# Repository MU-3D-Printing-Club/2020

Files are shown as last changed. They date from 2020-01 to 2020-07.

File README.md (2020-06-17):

# 2020
Meetings 2pm Thursday in E3508.

[Link to Ada Assembly instructions](https://openbionicslabs.com/obtutorials/ada-v1-assembly)

## Updates 2/27/2020
- Please remember to always **PULL FROM ORIGIN** and make a new branch before you make edits.
- Installed gitHub, Eagle, and SolidWorks on lab computer

## V2
Stuart's ARM board and probably Rust code.
- [x] Ask Dr. Gillis for review. (JD)
- [ ] Get rust code running for servos on discovery board. PWM libraries and also [potentiometer controlled feedback](https://www.actuonix.com/Actuonix-PQ-12-P-Linear-Actuator-p/pq12-p.htm). (Chris/Jake/Stuart/James/Matt)
- [x] Identify which rust-compatible chip to buy. (Jake/Stuart)
## V1
### V1.3 

Added [boost regulator](http://ww1.microchip.com/downloads/en/DeviceDoc/20005572A.pdf) in addition to 1.2 changes.  
- [ ] Review Ahmad's suggestions. Look in "Regulator" branch. (Jake/Ethan)
- [ ] Make Vcc route bigger.
### V1.2
Added [LiPo](https://cdn.sparkfun.com/assets/learn_tutorials/6/9/5/MCP738312.pdf) charger.

- [ ] Solder chip and resistors on.
- [ ] Burn bootloader and code. See if it works.
- [ ] Research new trigger algorithm. (James/Matt)
- [ ] Research custom myoelectric sensor. (Rosie)
- [ ] PALM DESIGN! (Chris, Hannah, Colm)
### V1.1
Reorganized PCB. Larger back cover.

- [ ] Document
- [ ] SHIP.
- [x] Tie knots. (Jack)
- [x] Solder myoelectric in.
- [x] Attach servos.
- [x] Print back cover.
- [x] Epoxy screw in.
- [x] Get the programmer out of reset mode. (Stuart)

### V1.0
From December. Broke because of lack and space/organization in back cover.

## V0
Bare bones code and prototype back cover. Cannot find Eagle file. Only legend speaks of this.

<pre>
.
├── Datasheets
│   ├── Actuonix+PQ12+Datasheet.pdf
│   ├── MCP73831.pdf
│   └── STM32F303.pdf
├── Myosensor
│   ├── Myosense.v1.brd
│   └── Myosense.v1.sch
├── Old
│   ├── Eagle Libraries
│   │   └── 3DPC.lbr
│   ├── Jig Components
│   │   ├── Legiment Jig.SLDPRT
│   │   └── Legiment Jig.STL
│   ├── eletronics test bed
│   │   ├── 400 point breadboard holder.stl
│   │   ├── STM32F3DISCOVERY holder.stl
│   │   ├── actuonix PQ12 servo holder.stl
│   │   ├── battery holder.stl
│   │   └── electronics v1.0 holder.stl
│   ├── v0.0
│   │   ├── SolidWorks
│   │   │   ├── Backcover 12-6-19.SLDPRT
│   │   │   └── Backcover 12-6-19.STL
│   │   ├── myoFlex-Original
│   │   │   └── myoFlex.ino
│   │   └── pcb
│   │       ├── circuitdraft.brd
│   │       ├── circuitdraft.sch
│   │       └── eagle.epf
│   ├── v0.1
│   │   └── PCB
│   │       ├── circuitdraft.brd
│   │       ├── circuitdraft.sch
│   │       └── eagle.epf
│   ├── v1.0
│   │   ├── PCB
│   │   │   ├── circuitdraft.brd
│   │   │   ├── circuitdraft.sch
│   │   │   └── eagle.epf
│   │   ├── PCB Libraries
│   │   │   ├── SamacSys_Parts.lbr
│   │   │   ├── TPS54627DDAR.lbr
│   │   │   ├── charger.lbr
│   │   │   ├── ind2.lbr
│   │   │   ├── inductor.lbr
│   │   │   ├── mega32U4.lbr
│   │   │   ├── microchip-update.lbr
│   │   │   └── powerPad.lbr
│   │   ├── SolidWorks
│   │   │   ├── 191216_Backcover_JD.SLDPRT
│   │   │   └── 191216_Backcover_JD.STL
│   │   ├── circuitdraft.txt
│   │   └── mainCode
│   │       └── mainCode.ino
│   ├── v1.1
│   │   ├── CAD
│   │   │   ├── 02_18_2020_BackcoverC.SLDPRT
│   │   │   ├── 02_18_2020_BackcoverF.SLDPRT
│   │   │   ├── 02_18_2020_BackcoverF.STL
│   │   │   ├── 2020_03_02_BackcoverShell.SLDPRT
│   │   │   ├── 203101_Backcover.SLDPRT
│   │   │   ├── Front Face Palm Screen Capture.PNG
│   │   │   ├── New Palm STL.STL
│   │   │   ├── New Palm.SLDPRT
│   │   │   ├── R_palm.SLDPRT
│   │   │   └── R_palm.stl
│   │   ├── Code
│   │   │   ├── Blink
│   │   │   │   └── Blink.ino
│   │   │   ├── helloWorld
│   │   │   │   └── helloWorld.ino
│   │   │   ├── mainCode
│   │   │   │   └── mainCode.ino
│   │   │   └── servoTest
│   │   │       └── servoTest.ino
│   │   └── PCB
│   │       ├── circuitdraft.brd
│   │       ├── circuitdraft.sch
│   │       └── eagle.epf
│   ├── v1.2
│   │   ├── Notes.txt
│   │   ├── PCB
│   │   │   ├── circuitdraft.brd
│   │   │   ├── circuitdraft.sch
│   │   │   └── eagle.epf
│   │   ├── mainCode
│   │   │   └── mainCode.ino
│   │   └── testLiPoCharger
│   │       └── testLiPoCharger.ino
│   ├── v1.3
│   │   ├── circuitdraft.brd
│   │   └── circuitdraft.sch
│   ├── v2.0
│   │   └── PCB
│   │       ├── Hand v2.0 parts.lib
│   │       ├── Hand v2.0-cache.lib
│   │       ├── Hand v2.0-rescue.dcm
│   │       ├── Hand v2.0.kicad_pcb
│   │       ├── Hand v2.0.kicad_pcb-bak
│   │       ├── Hand v2.0.net
│   │       ├── Hand v2.0.sch
│   │       ├── Hand v2.0.sch-bak
│   │       ├── fp-info-cache
│   │       ├── hand parts.bck
│   │       ├── hand parts.dcm
│   │       └── sym-lib-table
│   └── v2.1
│       └── PCB
│           ├── 2020-02-01_02-22-13
│           │   ├── 2020-02-01_02-22-13.lib
│           │   ├── footprints.pretty
│           │   │   └── STM32F302_303C2.kicad_mod
│           │   └── readme.txt
│           ├── Hand v2.1 parts.lib
│           ├── Hand v2.1-cache.lib
│           ├── Hand v2.1-rescue.dcm
│           ├── Hand v2.1-rescue.lib
│           ├── Hand v2.1.kicad_pcb
│           ├── Hand v2.1.kicad_pcb-bak
│           ├── Hand v2.1.net
│           ├── Hand v2.1.sch
│           ├── Hand v2.1.sch-bak
│           ├── fp-info-cache
│           ├── hand parts.bck
│           ├── hand parts.dcm
│           └── sym-lib-table
├── README.md
├── tree.txt
├── treeCMD.txt
└── v3.0
    └── hand v3.0
        ├── Hand Parts.bck
        ├── Hand Parts.dcm
        ├── Hand Parts.lib
        ├── fp-info-cache
        ├── hand v3.0-cache.lib
        ├── hand v3.0.kicad_pcb
        ├── hand v3.0.sch
        ├── hand v3.0.sch-bak
        ├── hand v3.xml
        └── sym-lib-table

38 directories, 103 files

</pre>
tree -I "*.pro|*.b#?|*.s#?|*.l?|*.job" -o tree.txt

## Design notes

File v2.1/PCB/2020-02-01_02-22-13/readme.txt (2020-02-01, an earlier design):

 

**********************************************************
*************  Important Instructions Follow  ************
**********************************************************
 
All files exported to: C:\UltraLibrarian\Library\Exported\KiCad\2020-02-01_02-22-13\2020-02-01_02-22-13\2020-02-01_02-22-13.lib

After you have used Ultra Librarian to export library:
**************************************************
**To import your new library symbols into KiCad:**
**************************************************
1. Open KiCad.
2. On the program/tool list, select the Symbol Library Editor.
3. In the Symbol Library Editor, select 'Add an existing library' from the symbol menu or "Add Library" from the File menu.
4. From here select the library you wish to add.
5. Now select if you would like the library accessible globaly or for the current project.
6. Browsing the list of libraries, you should see the newly imported library!

**************************************************************
**To import your new library footprints/patterns into KiCad:**
**************************************************************
1. Open KiCad.
2. On the program/tool list, go to Pcbnew, or simply open the footprint editor.
3. Select the "import footprint" icon then select the *.kicad_mod* file of the footprint to be imported.
4. You have now successfully imported your new footprint/pattern.

**************************************************************
**    !!!!!!!!!!!!!        WARNING        !!!!!!!!!!!!!     **
**************************************************************
KiCAD does not support filled/hatched polygons on footprints!
All polygons will be represented with an outline made of lines in each design.
Etch polygons will be drawn on the documentation layer, "Dwgs.User", and can be filled during board creation.

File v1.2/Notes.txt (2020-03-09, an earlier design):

1. Buy higher geared servos
2. Make algorithm not move all hands at the same time.
3. Make power path bigger.

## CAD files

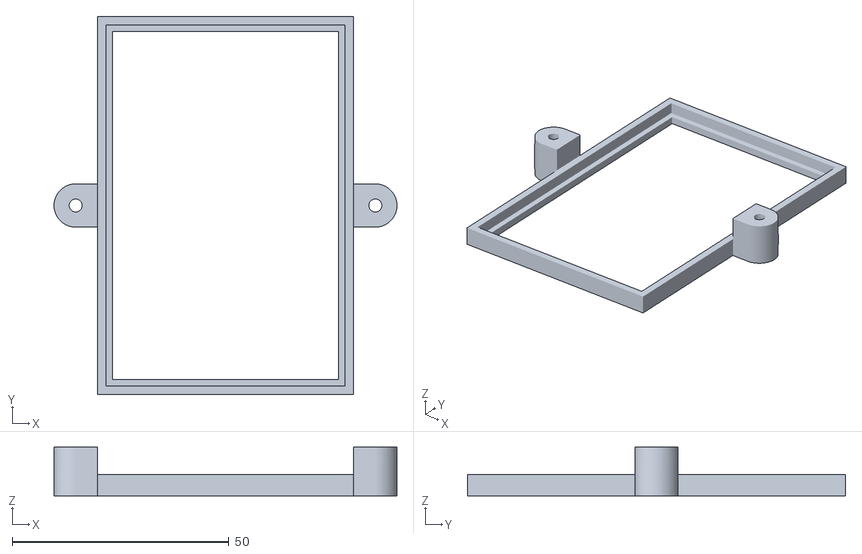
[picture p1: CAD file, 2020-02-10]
eletronics test bed/400 point breadboard holder.stl
79.2 x 87.3 x 11.3

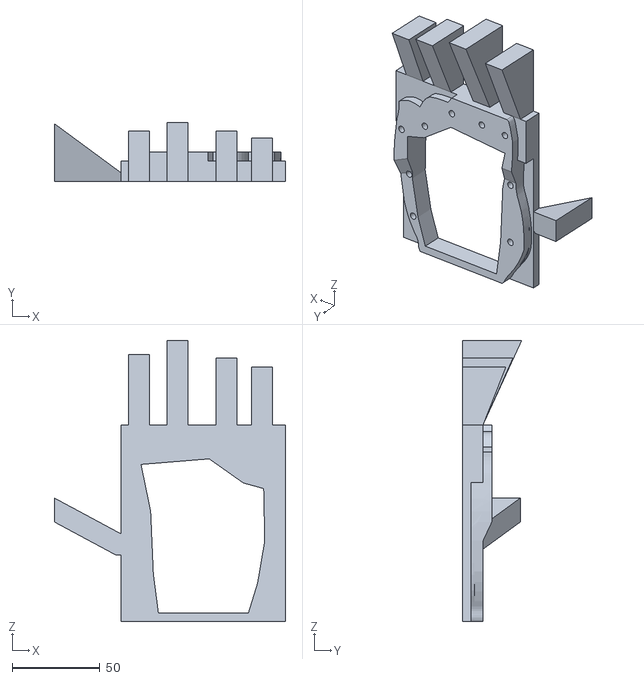
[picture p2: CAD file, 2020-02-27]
Jig Components/Legiment Jig.STL
131.5 x 33.8 x 159.9

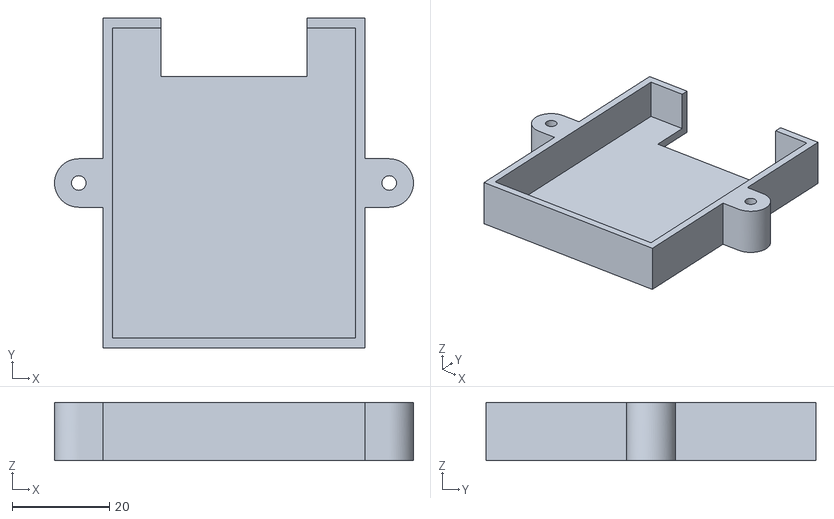
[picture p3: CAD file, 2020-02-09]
eletronics test bed/battery holder.stl
74.0 x 68.0 x 12.0

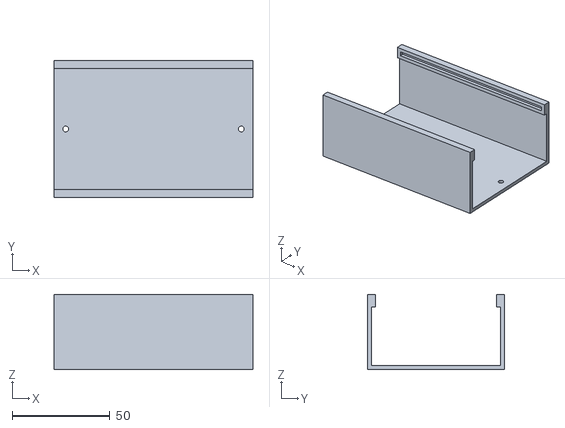
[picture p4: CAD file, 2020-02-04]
eletronics test bed/STM32F3DISCOVERY holder.stl
102.0 x 70.0 x 38.5

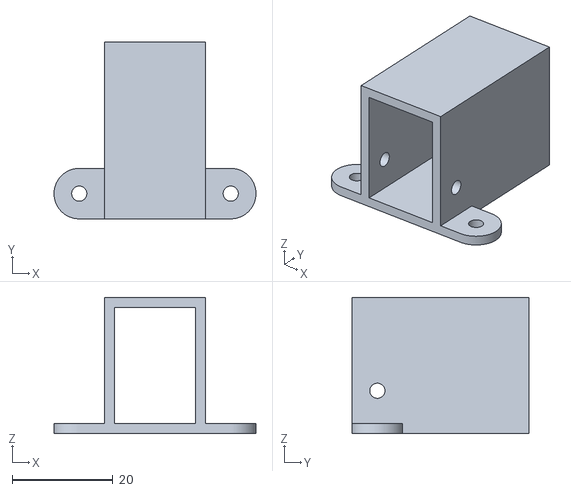
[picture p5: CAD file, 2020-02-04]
eletronics test bed/actuonix PQ12 servo holder.stl
40.0 x 35.0 x 27.0

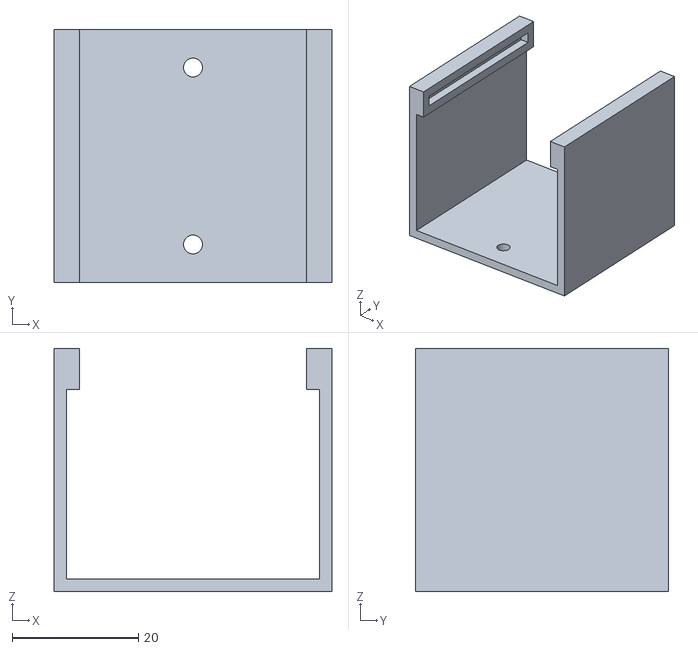
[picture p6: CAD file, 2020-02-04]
eletronics test bed/electronics v1.0 holder.stl
44.0 x 40.0 x 38.5

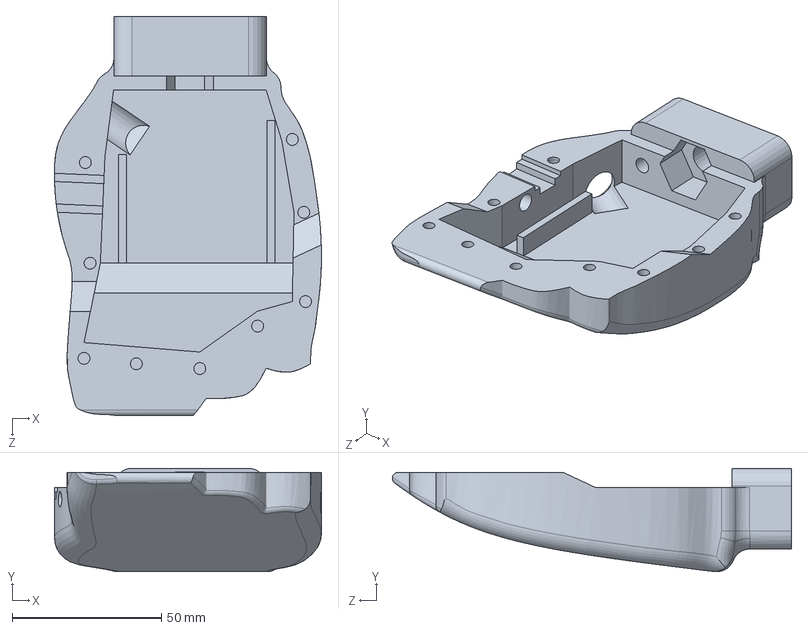
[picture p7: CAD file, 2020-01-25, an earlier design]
Old/v0.0/SolidWorks/Backcover 12-6-19.SLDPRT
89.5 x 34.7 x 133.9 mm

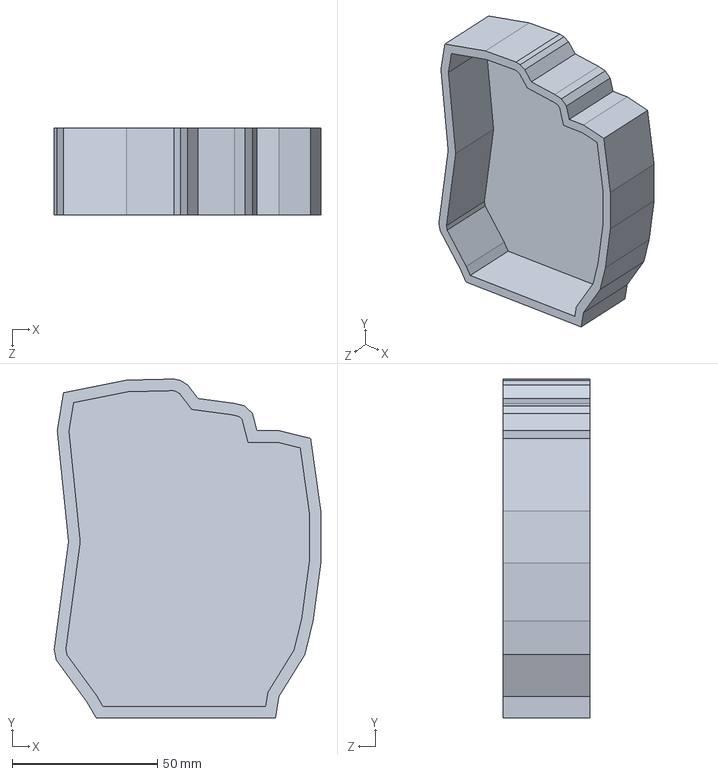
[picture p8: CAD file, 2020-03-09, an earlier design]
Old/v1.1/CAD/New Palm.SLDPRT
91.8 x 116.6 x 30.0 mm

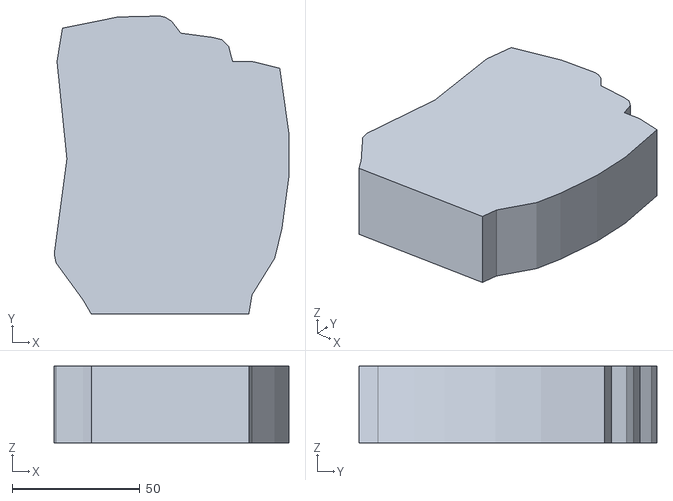
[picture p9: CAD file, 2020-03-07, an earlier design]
Old/v1.1/CAD/New Palm STL.STL
91.8 x 116.6 x 30.0

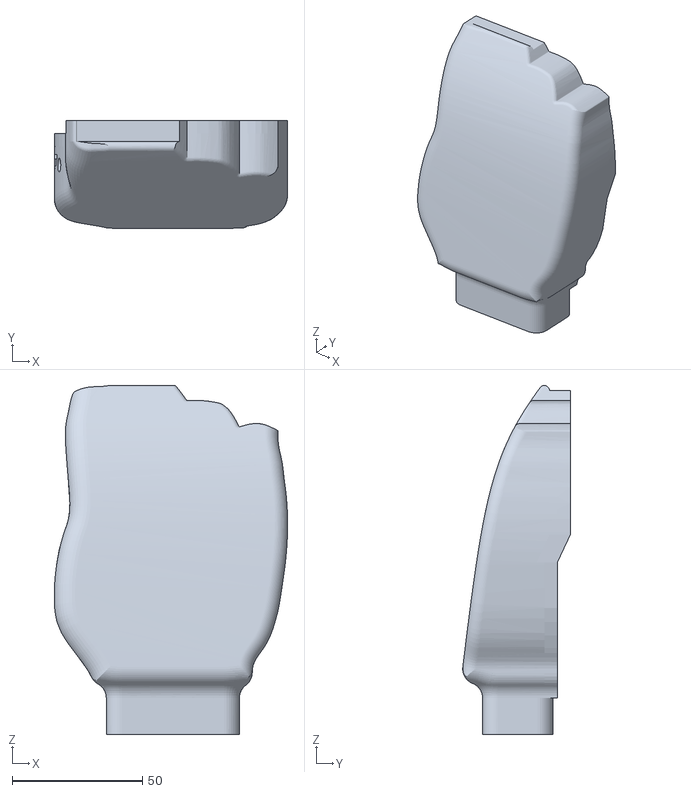
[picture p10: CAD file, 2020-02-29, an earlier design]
Old/v1.1/CAD/02_18_2020_BackcoverF.STL
89.5 x 41.3 x 133.9

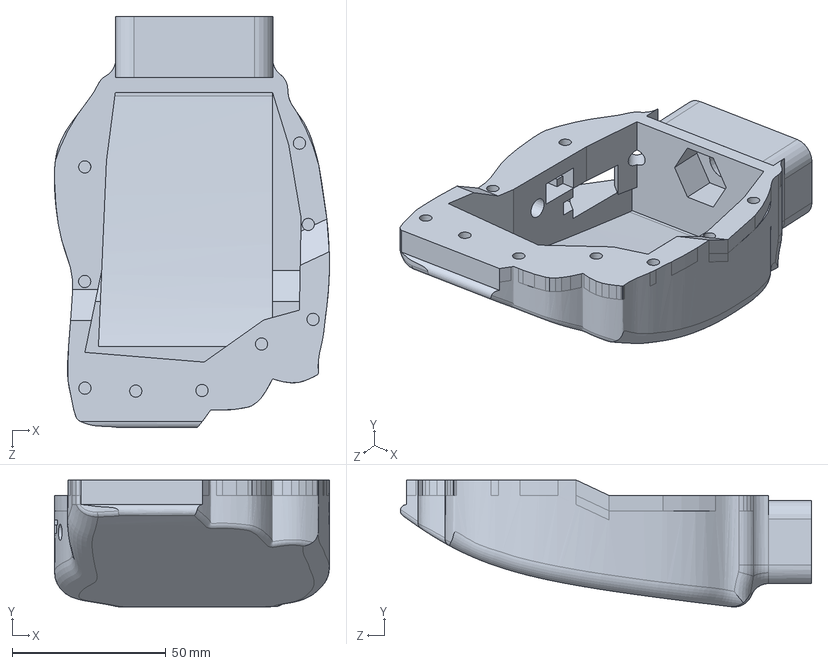
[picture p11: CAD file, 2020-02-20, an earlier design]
v1.1/CAD/02_18_2020_BackcoverF.SLDPRT
89.5 x 41.3 x 133.9 mm

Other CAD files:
Old/v0.0/SolidWorks/Backcover 12-6-19.STL
Old/v1.0/SolidWorks/191216_Backcover_JD.SLDPRT
Old/v1.0/SolidWorks/191216_Backcover_JD.STL
Old/v1.1/CAD/2020_03_02_BackcoverShell.SLDPRT
Old/v1.1/CAD/203101_Backcover.SLDPRT
v0.0/SolidWorks/Backcover 12-6-19.STL
v1.0/SolidWorks/191216_Backcover_JD.STL
v1.1/CAD/2020_03_02_BackcoverShell.SLDPRT
v1.1/CAD/203101_Backcover.SLDPRT

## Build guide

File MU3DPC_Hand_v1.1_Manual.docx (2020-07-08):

University of Missouri

College of Engineering

3D Printing Club

Stuart Aldrich, Chris Scully, Andrew Dove, Jack Allen, Rose Schauffler, Ahmad Suliman, J.D. Peiffer

## Printed Materials

The palm is printed using NinjaFlex TPU filament and an OpenBionics Ada v1.1 design. The back cover is a custom design printed with PLA filament. Files can be found on the club GitHub repository (https://github.com/MU-3D-Printing-Club/2020/tree/master/Old/v1.1). A M8 screw extends from the back cover for socket attachment.

## Electronics Hardware

The interior of the hand houses three main circuit boards and a battery. First, the micro-USB port on the exterior of the hand is connected to a LiPo charging board to manage charging and protect the 3.7 V, 2000 mAh Lithium Polymer battery. Charging will take an estimated 4 hours from a completely empty battery. The battery will power the circuitry in standby for an estimated 20 hours, but for much shorter depending on hand use. Hand contraction draws 1.5 A of current for ~1 second, thus enabling an estimated ~3,000 contractions on a charge. This has not been verified yet.

Battery voltage is stepped up to 5V using a boost converter and routed to our main control board. This PCB hosts an ATmega32u4 using burned with an Arduino bootloader (See code section of repository). This microcontroller takes input from the myoelectric (red) EMG sensor and toggles servos (fingers) between in and out positions. The myoelectric is traditionally attached along the bicep, with the black electrode grounded on the elbow bone, or on another muscle, but any muscle can work. Further documentation about the myosensor and attachment can be found here (https://github.com/MU-3D-Printing-Club/2020/blob/master/Datasheets/Myosensor.pdf) and at the end of this document.

Peripherals also include a power switch, status LED, and hold button. The hold button, located near the pointer finger knuckle, simply holds the hand in the current state regardless of myoelectric input.

The power switch, located at the base of the thumb, for unknown reasons, takes two cycles to turn on. The first on switch will turn the status LED bright blue. Simply turn the switch back off and then back on. The status LED should now begin to blink a less intense blue.

## Software

When the status LED blinks blue, the hand is in training mode. This is only entered right as the hand turns on. The hand will remain in this mode until it has processed three contractions (or spikes of EMG signal). These contractions will not toggle the finger position. How intense contractions are made during this time determines the activation threshold value, so one should not flex as hard as they can or too lightly. After three contractions, the hand enters standard operation mode. This is characterized by a red/green blink every 10 seconds. Now, the hand will toggle between open and closed states in response to a spike in the myoelectric. There is no difference between action to open/close the hand, nor is there a method to close the hand part way.

## Future Directions

For the next iteration, we intend to incorporate position feedback into the motors controlling the fingers—this way, the motors will “know” when to stop grabbing and the user will have the opportunity for feedback as well.

We have also designed a myoelectric sensor so this design will not have to rely on a third-party sensor. In addition, a myoelectric sleeve may be more comfortable and functional for the user.

Wrist attachment of the prosthetic will need to be a topic of further discussion.

The total cost of the hand is slightly under $500 USD and is largely due to the $350 USD cost of the servos. Ideas to lower this cost have been presented but may limit controllability and feedback options.

We welcome any feedback and are already working on a lower-profile, faster, more intelligent version.

## EMG Placement

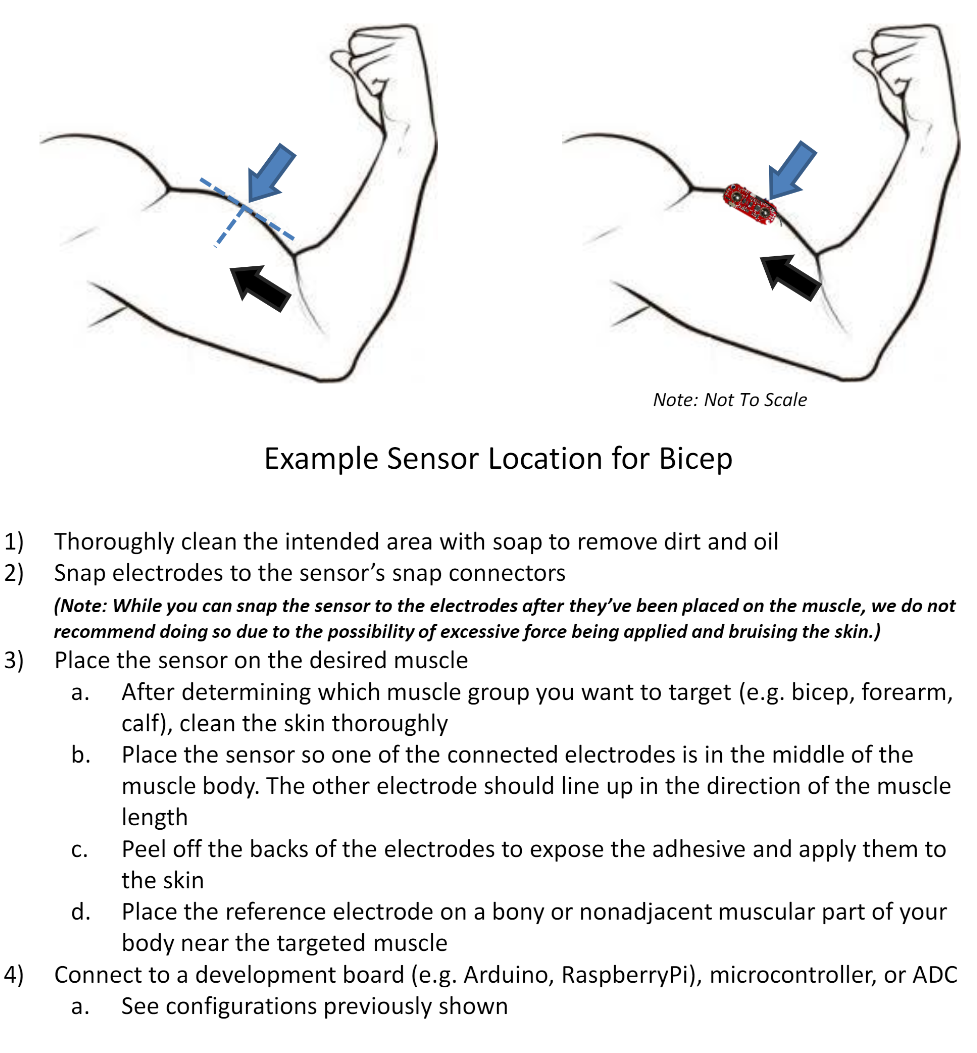
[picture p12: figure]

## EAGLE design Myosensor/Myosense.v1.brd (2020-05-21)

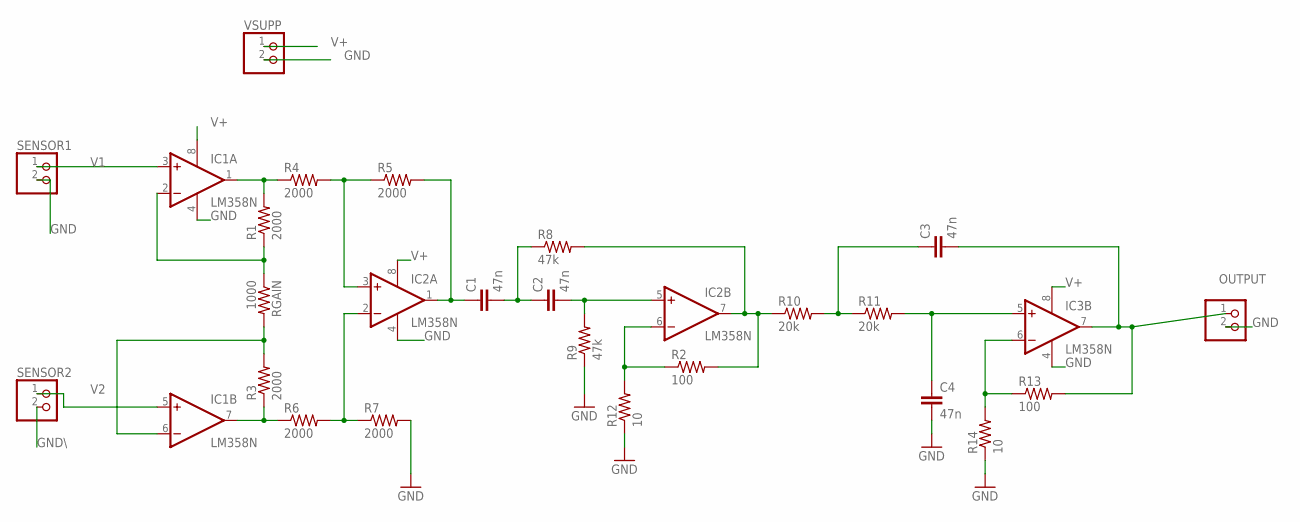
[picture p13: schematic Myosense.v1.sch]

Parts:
C1, C2, C3, C4: 47n; C2.5-3
IC1, IC2, IC3: LM358N; DIL08
OUTPUT: PINHD-1X2; 1X02
R1, R3, R4, R5, R6, R7: 2000; 0204/5
R2, R13: 100; 0204/5
R8, R9: 47k; 0204/5
R10, R11: 20k; 0204/5
R12, R14: 10; 0204/5
RGAIN: 1000; 0204/5
SENSOR1, SENSOR2: PINHD-1X2; 1X02
VSUPP: PINHD-1X2; 1X02

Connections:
GND: C4.2, IC1.4 (V-), IC2.4 (V-), IC3.4 (V-), OUTPUT.2, R7.2, R9.1, R12.1, R14.1, SENSOR1.2, VSUPP.2
GND\: SENSOR2.2
unnamed: IC1.1 (OUT), R1.2, R4.1
unnamed: IC1.2 (-IN), R1.1, RGAIN.1
unnamed: IC1.6 (-IN), R3.2, RGAIN.2
unnamed: IC2.3 (+IN), R4.2, R5.1
unnamed: IC1.7 (OUT), R3.1, R6.1
unnamed: IC2.2 (-IN), R6.2, R7.1
unnamed: C1.1, IC2.1 (OUT), R5.2
unnamed: C1.2, C2.1, R8.1
unnamed: C2.2, IC2.5 (+IN), R9.2
unnamed: IC2.7 (OUT), R2.2, R8.2, R10.1
unnamed: IC2.6 (-IN), R2.1, R12.2
unnamed: C3.1, R10.2, R11.1
unnamed: C4.1, IC3.5 (+IN), R11.2
unnamed: IC3.6 (-IN), R13.1, R14.2
unnamed: C3.2, IC3.7 (OUT), OUTPUT.1, R13.2
V1: IC1.3 (+IN), SENSOR1.1
V2: IC1.5 (+IN), SENSOR2.1
V+: IC1.8 (V+), IC2.8 (V+), IC3.8 (V+), VSUPP.1

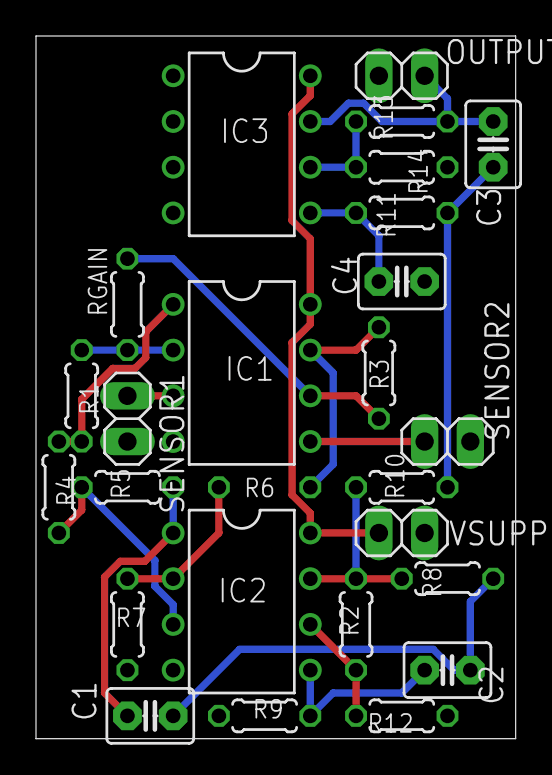
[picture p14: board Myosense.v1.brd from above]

Board: 2 copper layers, 26.7 x 39.0 mm, 26 parts (1 on the bottom side), 19 nets.

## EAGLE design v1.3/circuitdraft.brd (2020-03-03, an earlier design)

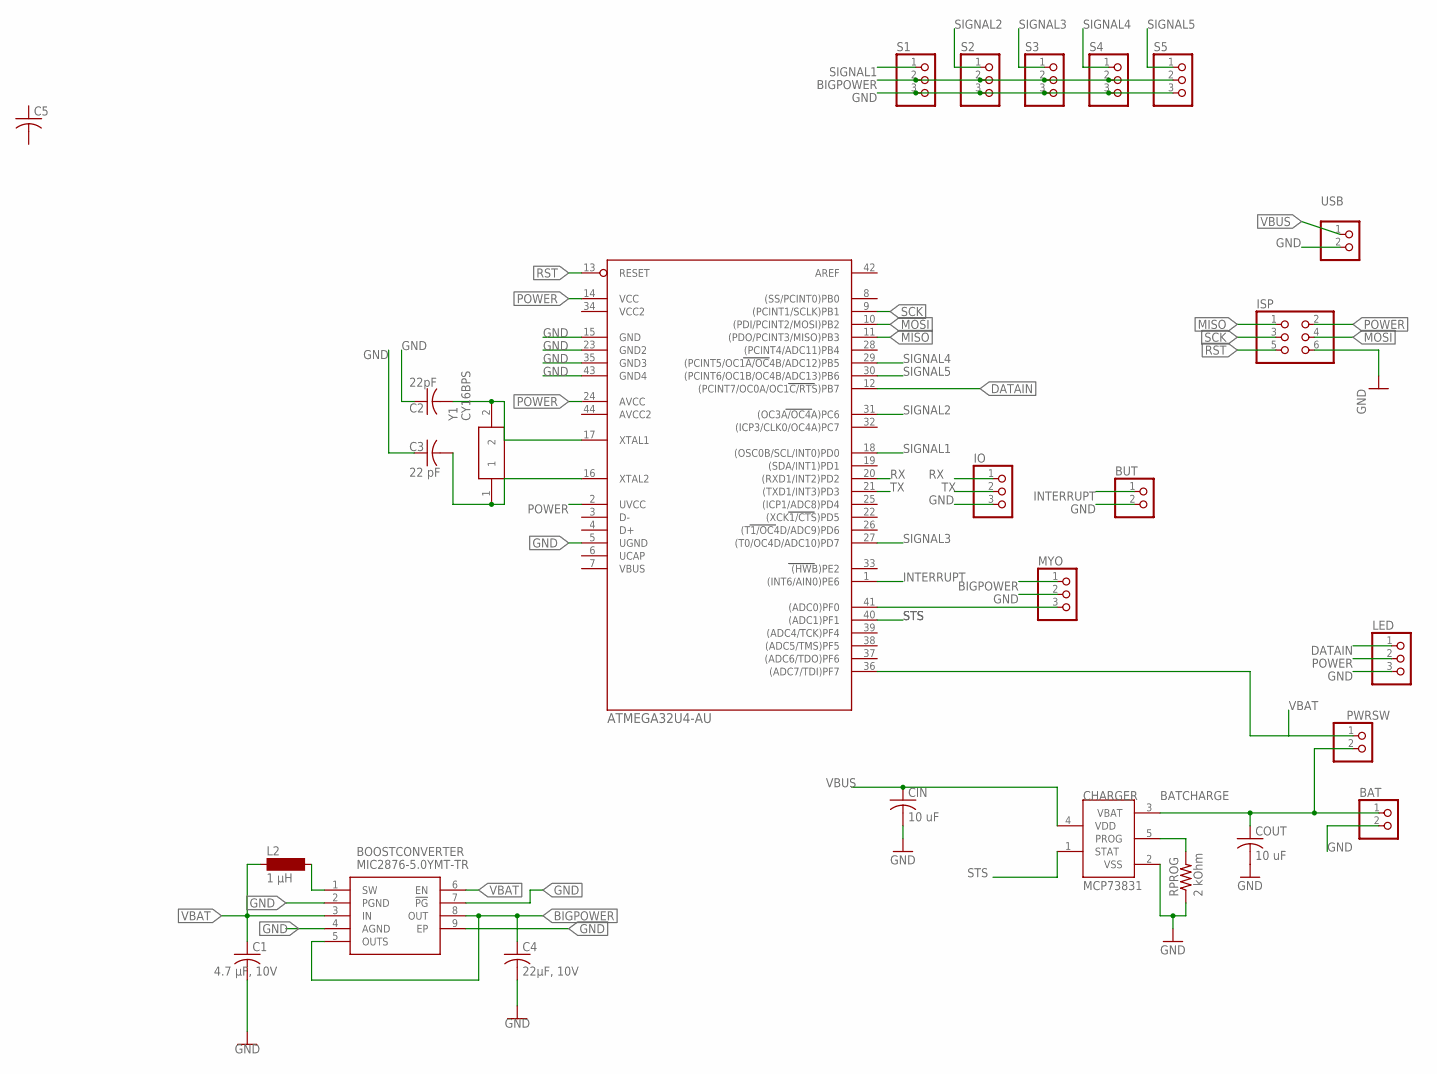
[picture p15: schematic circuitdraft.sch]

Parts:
BAT: PINHD-1X2; 1X02
BOOSTCONVERTER: MIC2876-5.0YMT-TR; MIC287650YMTTR
BUT: PINHD-1X2; 1X02
C1: 4.7 μF, 10V; C0603
C2: 22pF; C025-024X044
C3: 22 pF; C025-024X044
C4: 22μF, 10V; C0603
C5: C-USC0603; C0603
CHARGER: MCP73831; SOT23-5L
CIN: 10 uF; C0603
COUT: 10 uF; C0603
IO: PINHD-1X3; 1X03
ISP: PINHD-2X3; 2X03
L2: 1 μH; SD75
LED: PINHD-1X3; 1X03
MYO: PINHD-1X3; 1X03
PWRSW: PINHD-1X2; 1X02
RPROG: 2 kOhm; R0603
S1, S2, S3, S4, S5: PINHD-1X3; 1X03
U$1: ATMEGA32U4-AU; TQFP44
USB: PINHD-1X2; 1X02
Y1: CY16BPS

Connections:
BATCHARGE: BAT.1, CHARGER.3 (VBAT), COUT.1, PWRSW.2
BIGPOWER: BOOSTCONVERTER.5 (OUTS), BOOSTCONVERTER.8 (OUT), C4.1, MYO.1, S1.2, S2.2, S3.2, S4.2, S5.2
DATAIN: LED.1, U$1.12 ((PCINT7/OC0A/OC1C/RTS)PB7)
GND: BAT.2, BOOSTCONVERTER.2 (PGND), BOOSTCONVERTER.4 (AGND), BOOSTCONVERTER.7 (!PG), BOOSTCONVERTER.9 (EP), BUT.2, C1.2, C2.1, C3.1, C4.2, CHARGER.2 (VSS), CIN.2, COUT.2, IO.3, ISP.6, LED.3, MYO.2, RPROG.1, S1.3, S2.3, S3.3, S4.3, S5.3, U$1.5 (UGND), U$1.15 (GND), U$1.23 (GND2), U$1.35 (GND3), U$1.43 (GND4), USB.2
INTERRUPT: BUT.1, U$1.1 ((INT6/AIN0)PE6)
MISO: ISP.1, U$1.11 ((PDO/PCINT3/MISO)PB3)
MOSI: ISP.4, U$1.10 ((PDI/PCINT2/MOSI)PB2)
unnamed: MYO.3, U$1.41 ((ADC0)PF0)
unnamed: BOOSTCONVERTER.1 (SW), L2.2
unnamed: CHARGER.5 (PROG), RPROG.2
unnamed: C2.2, U$1.17 (XTAL1), Y1.2
unnamed: C3.2, U$1.16 (XTAL2), Y1.1
POWER: ISP.2, LED.2, U$1.2 (UVCC), U$1.14 (VCC), U$1.24 (AVCC)
RST: ISP.5, U$1.13 (RESET)
RX: IO.1, U$1.20 ((RXD1/INT2)PD2)
SCK: ISP.3, U$1.9 ((PCINT1/SCLK)PB1)
SIGNAL1: S1.1, U$1.18 ((OSC0B/SCL/INT0)PD0)
SIGNAL2: S2.1, U$1.31 ((OC3A/OC4A)PC6)
SIGNAL3: S3.1, U$1.27 ((T0/OC4D/ADC10)PD7)
SIGNAL4: S4.1, U$1.29 ((PCINT5/OC1A/OC4B/ADC12)PB5)
SIGNAL5: S5.1, U$1.30 ((PCINT6/OC1B/OC4B/ADC13)PB6)
STS: CHARGER.1 (STAT), U$1.40 ((ADC1)PF1)
TX: IO.2, U$1.21 ((TXD1/INT3)PD3)
VBAT: BOOSTCONVERTER.3 (IN), BOOSTCONVERTER.6 (EN), C1.1, L2.1, PWRSW.1, U$1.36 ((ADC7/TDI)PF7)
VBUS: CHARGER.4 (VDD), CIN.1, USB.1

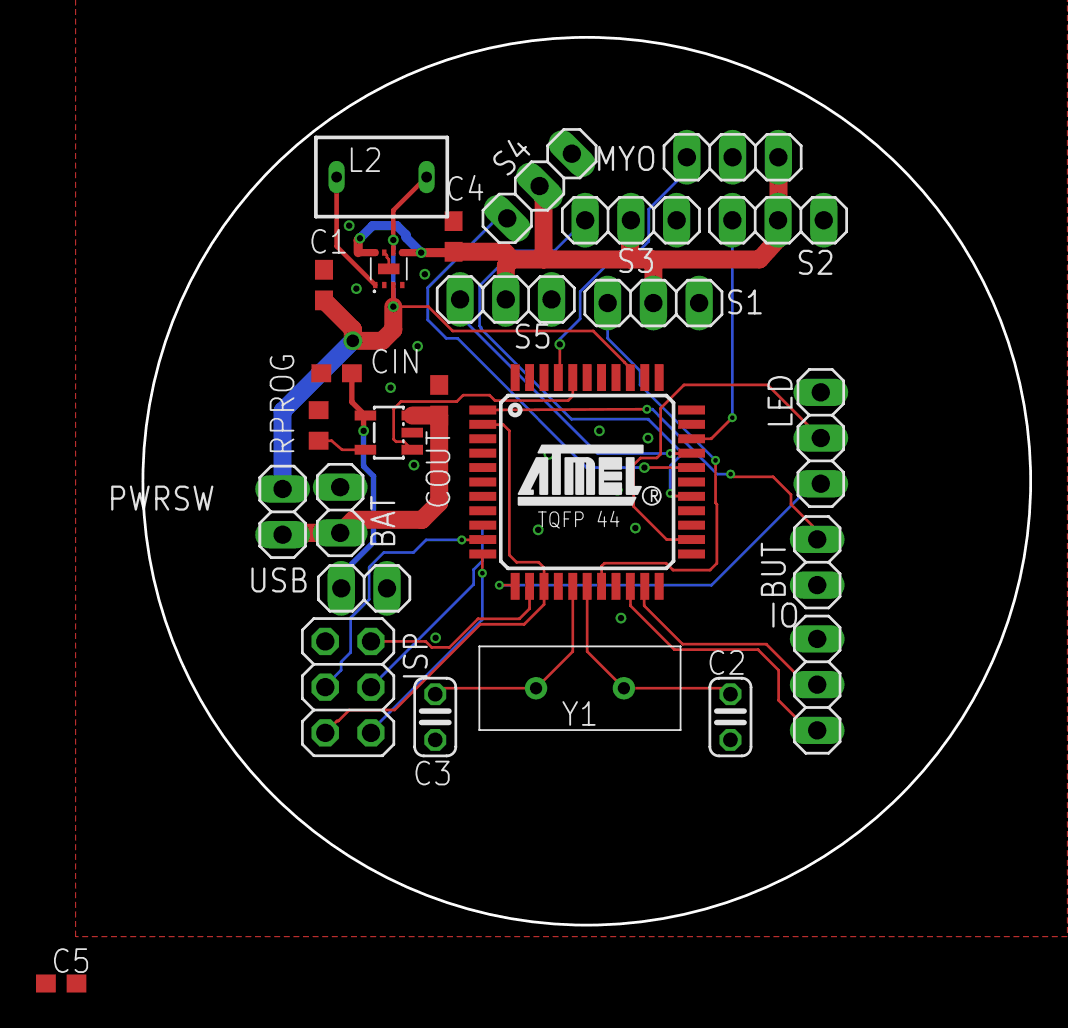
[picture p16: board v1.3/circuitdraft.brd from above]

Board: 2 copper layers, 49.3 x 49.3 mm, 26 parts (0 on the bottom side), 25 nets.

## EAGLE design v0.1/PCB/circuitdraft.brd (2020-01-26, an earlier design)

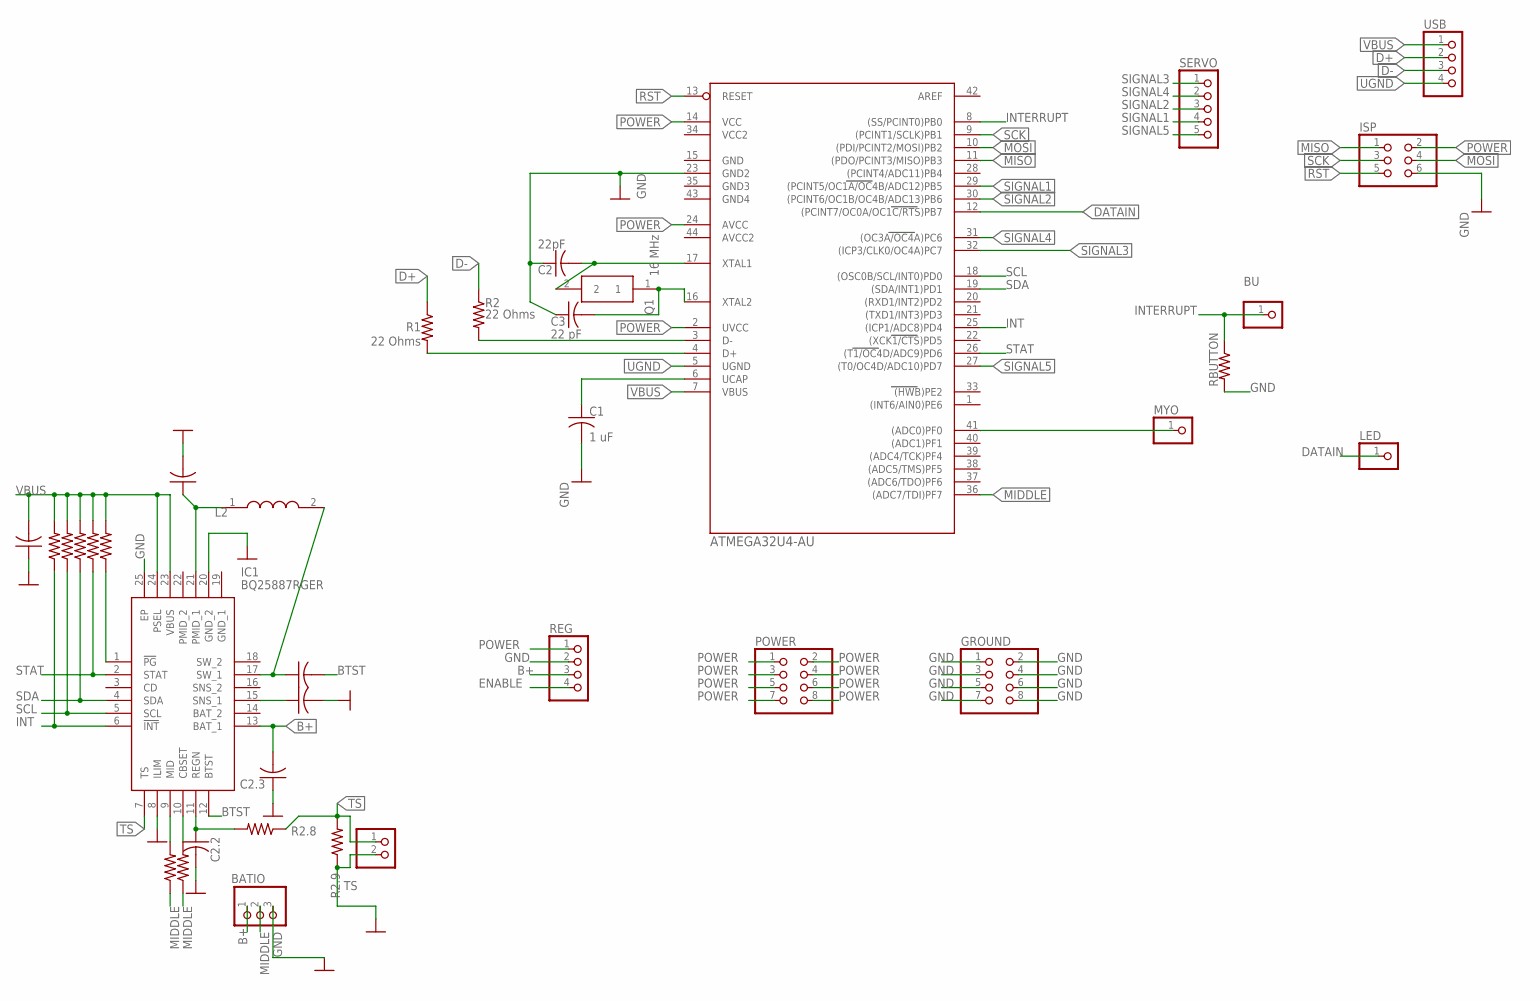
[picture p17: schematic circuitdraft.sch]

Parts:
BATIO: PINHD-1X3; 1X03
BU: PINHD-1X1; 1X01
C1, C2.1, C2.3: 1 uF; C0603
C2: 22pF; C0603
C2.2: 4.7 uF; C0603
C2.4: 44 uF; C0603
C2.5: 47 nF; C0603
C2.6: 10 uF; C0603
C3: 22 pF; C0603
GROUND: PINHD-2X4; 2X04
IC1: BQ25887RGER; QFN50P400X400X100-25N
ISP: PINHD-2X3; 2X03
L2: 1 uH; INDC2016X100N
LED: PINHD-1X1; 1X01
MYO: PINHD-1X1; 1X01
POWER: PINHD-2X4; 2X04
Q1: 16 MHz; ECS2501823GJGNTR
R1, R2: 22 Ohms; R0603
R2.1, R2.2, R2.3, R2.4, R2.5: 10000 Ohms; R0603
R2.6: 300 Ohms; R0603
R2.7: 12 Ohms; R0603
R2.8: 5.23 kOhms; R0603
R2.9: 30.1 kOhms; R0603
RBUTTON: 220 Ohm; R0603
REG: PINHD-1X4; 1X04
SERVO: PINHD-1X5; 1X05
TS: PINHD-1X2; 1X02
U$1: ATMEGA32U4-AU; TQFP44
USB: PINHD-1X4; 1X04

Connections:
B+: BATIO.1, C2.3.2, IC1.13 (BAT_1), REG.3
BTST: C2.5.2, IC1.12 (BTST)
D+: R1.1, USB.2
D-: R2.1, USB.3
DATAIN: LED.1, U$1.12 ((PCINT7/OC0A/OC1C/RTS)PB7)
ENABLE: REG.4
GND: BATIO.3, C1.2, C2.1, C2.1.1, C2.2.2, C2.3.1, C2.4.2, C2.6.2, C3.1, GROUND.1, GROUND.2, GROUND.3, GROUND.4, GROUND.5, GROUND.6, GROUND.7, GROUND.8, IC1.8 (ILIM), IC1.20 (GND_2), IC1.25 (EP), ISP.6, R2.9.1, RBUTTON.2, REG.2, TS.2, U$1.23 (GND2)
INT: IC1.6 (!INT), R2.1.1, U$1.25 ((ICP1/ADC8)PD4)
INTERRUPT: BU.1, RBUTTON.1, U$1.8 ((SS/PCINT0)PB0)
MIDDLE: BATIO.2, R2.6.1, R2.7.1, U$1.36 ((ADC7/TDI)PF7)
MISO: ISP.1, U$1.11 ((PDO/PCINT3/MISO)PB3)
MOSI: ISP.4, U$1.10 ((PDI/PCINT2/MOSI)PB2)
MYOSIGNAL: MYO.1, U$1.41 ((ADC0)PF0)
unnamed: R2.2, U$1.3 (D-)
unnamed: IC1.10 (CBSET), R2.7.2
unnamed: R1.2, U$1.4 (D+)
unnamed: C3.2, Q1.1, U$1.16 (XTAL2)
unnamed: C2.2, Q1.2, U$1.17 (XTAL1)
unnamed: IC1.1 (!PG), R2.5.1
unnamed: C1.1, U$1.6 (UCAP)
unnamed: IC1.9 (MID), R2.6.2
unnamed: C2.5.1, IC1.17 (SW_1), L2.2
unnamed: C2.2.1, IC1.11 (REGN), R2.8.2
unnamed: C2.4.1, IC1.15 (SNS_1)
unnamed: C2.6.1, IC1.21 (PMID_1), L2.1
POWER: ISP.2, POWER.1, POWER.2, POWER.3, POWER.4, POWER.5, POWER.6, POWER.7, POWER.8, REG.1, U$1.2 (UVCC), U$1.14 (VCC), U$1.24 (AVCC)
RST: ISP.5, U$1.13 (RESET)
SCK: ISP.3, U$1.9 ((PCINT1/SCLK)PB1)
SCL: IC1.5 (SCL), R2.2.1, U$1.18 ((OSC0B/SCL/INT0)PD0)
SDA: IC1.4 (SDA), R2.3.1, U$1.19 ((SDA/INT1)PD1)
SIGNAL1: SERVO.4, U$1.29 ((PCINT5/OC1A/OC4B/ADC12)PB5)
SIGNAL2: SERVO.3, U$1.30 ((PCINT6/OC1B/OC4B/ADC13)PB6)
SIGNAL3: SERVO.1, U$1.32 ((ICP3/CLK0/OC4A)PC7)
SIGNAL4: SERVO.2, U$1.31 ((OC3A/OC4A)PC6)
SIGNAL5: SERVO.5, U$1.27 ((T0/OC4D/ADC10)PD7)
STAT: IC1.2 (STAT), R2.4.1, U$1.26 ((T1/OC4D/ADC9)PD6)
TS: IC1.7 (TS), R2.8.1, R2.9.2, TS.1
UGND: U$1.5 (UGND), USB.4
VBUS: C2.1.2, IC1.23 (VBUS), IC1.24 (PSEL), R2.1.2, R2.2.2, R2.3.2, R2.4.2, R2.5.2, U$1.7 (VBUS), USB.1

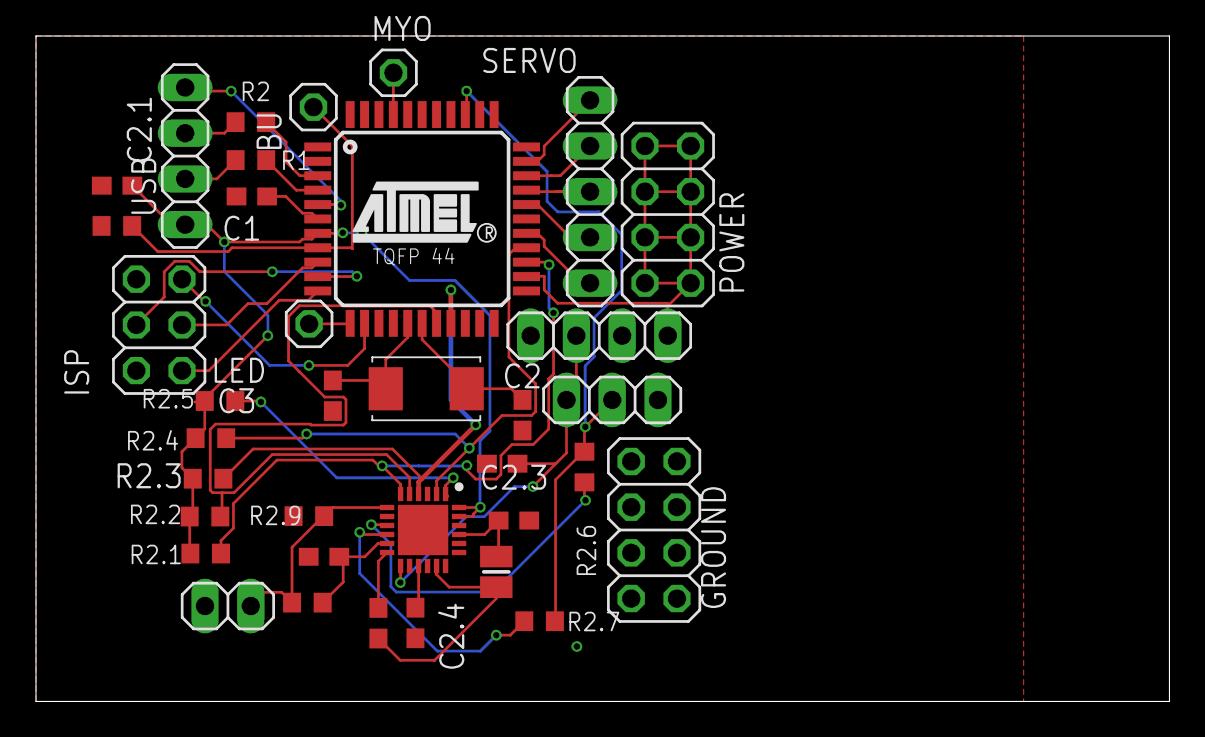
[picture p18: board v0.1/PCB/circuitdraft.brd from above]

Board: 2 copper layers, 63.0 x 37.0 mm, 36 parts (0 on the bottom side), 38 nets.

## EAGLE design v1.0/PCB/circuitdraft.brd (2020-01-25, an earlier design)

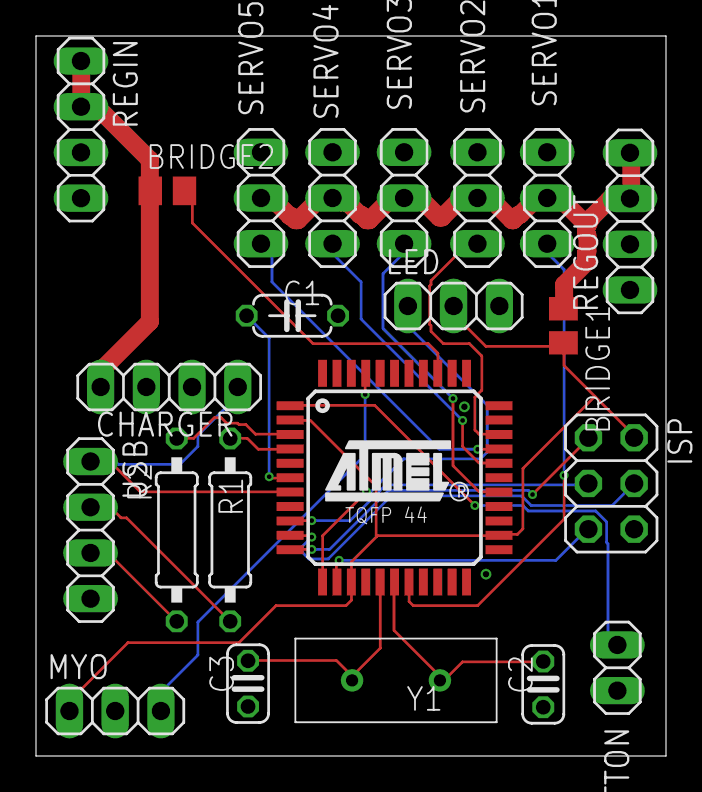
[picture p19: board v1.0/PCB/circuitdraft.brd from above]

Board: 2 copper layers, 35.0 x 40.0 mm, 22 parts (0 on the bottom side), 25 nets.

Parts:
BRIDGE1, BRIDGE2: M0805
BUTTON: 1X02
C1: 1 uF; C050-024X044
C2: 22pF; C025-024X044
C3: 22 pF; C025-024X044
CHARGER: 1X04
ISP: 2X03
LED: 1X03
MYO: 1X03
R1, R2: 22 Ohms; 0207/10
REGIN: 1X04
REGOUT: 1X04
SERVO1, SERVO2, SERVO3, SERVO4, SERVO5: 1X03
U$1: ATMEGA32U4-AU; TQFP44
USB: 1X04
Y1: CY16BPS

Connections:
BIGPOWER: BRIDGE1.1, REGOUT.3, REGOUT.4, SERVO1.2, SERVO2.2, SERVO3.2, SERVO4.2, SERVO5.2
D+: R1.1, USB.2
D-: R2.1, USB.3
DATAIN: LED.1, U$1.12
GND: BUTTON.2, C1.2, C2.1, C3.1, CHARGER.2, CHARGER.3, ISP.6, LED.3, MYO.2, REGIN.3, REGIN.4, REGOUT.1, REGOUT.2, SERVO1.3, SERVO2.3, SERVO3.3, SERVO4.3, SERVO5.3, U$1.5, U$1.15, U$1.23, U$1.35, U$1.43, USB.4
INTERRUPT: BUTTON.1, U$1.1
MISO: ISP.1, U$1.11
MOSI: ISP.4, U$1.10
unnamed: MYO.3, U$1.41
unnamed: R2.2, U$1.3
unnamed: C1.1, U$1.6
unnamed: R1.2, U$1.4
unnamed: C2.2, U$1.17, Y1.2
unnamed: C3.2, U$1.16, Y1.1
unnamed: BRIDGE2.2, U$1.36
POWER: BRIDGE1.2, ISP.2, LED.2, MYO.1, U$1.2, U$1.14, U$1.24
RST: ISP.5, U$1.13
SCK: ISP.3, U$1.9
SIGNAL1: SERVO1.1, U$1.18
SIGNAL2: SERVO2.1, U$1.31
SIGNAL3: SERVO3.1, U$1.27
SIGNAL4: SERVO4.1, U$1.29
SIGNAL5: SERVO5.1, U$1.30
VBAT: BRIDGE2.1, CHARGER.4, REGIN.1, REGIN.2
VBUS: CHARGER.1, U$1.7, USB.1

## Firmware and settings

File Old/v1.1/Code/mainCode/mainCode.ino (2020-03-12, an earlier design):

//this code takes input from a myoelctric and toggles the hand between the contracted
// and extended positions when there is a spike above a user-defined level
// future projects will include running this code with low power

#include <Adafruit_NeoPixel.h>
#include <Servo.h>     //library used for servos

Servo thumb;            //defines the name of the five servos and them as servo objects
Servo pointer;
Servo middle;
Servo ring;
Servo pinky;


#define extendmin 2000    //static integers of extendminimum and extendmaximum servo extension
#define extendmax 1000

#define setmin 1850
#define setmax 1000

int trigger = 600; //default value incase if all fails
int rotation = 2; //set to 4 for more opitons
bool isLocked = false; //0 is not locked
bool isIniting = true;

enum pins
{
  THUMB_PIN = 9,
  INDEX_PIN = 5,
  MIDDLE_PIN = 6,
  RING_PIN = 3,
  PINKY_PIN = 10,
  VBAT_PIN = A0,
  MYO_PIN = A5,
  LED_PIN = 11,
  BUTTON_PIN = 7
};

enum hand_state
{
  OPEN, FIST, POINT, PINCH
};

Adafruit_NeoPixel led(1, LED_PIN, NEO_RGB + NEO_KHZ800);

#define overload 1028

int state = OPEN;    // sets default state to be open
#define threshold .4    // this is the percentage of the extendmax read we use to define a flex

int setTrigger();
bool check(int);
void collect(int *, int *, int *);
void handPosition(int, int, int, int, int);
void locked();
void set_led();

//wait 10 seconds then set led color for 1 second based on battery voltage
ISR(TIMER3_OVF_vect)
{
  static char count = -1;

  if (isIniting) {
    count = ++count % 4;
    if (count < 2)
      led.setPixelColor(0, 0, 0, 20);
    else
      led.setPixelColor(0, 0, 0, 0);
  } else {
    count = ++count % 40; // 0.1hz real
    //count = ++count % 8; // 1hz test
    if (count < 4) {
      const float battery_voltage = analogRead(VBAT_PIN) * 0.0049; //not reading reliably
      //const float battery_voltage = 2.5; test code

      const float normalized = battery_voltage - 3.0;

      float light_level = 20.0 * normalized;

      light_level = light_level < 0.0 ? 0.0 : light_level;
      light_level = light_level > 20.0 ? 20.0 : light_level;

      led.setPixelColor(0, 20.0 - light_level, light_level, 0);

      Serial1.print("Battery Voltage: ");
      Serial1.println(battery_voltage);
    } else
      led.setPixelColor(0, 0, 0, 0);
  }
  led.show();
}

// THIS PART ONLY RUNS ONCE
void setup() {
  isIniting = true;

  led.begin();
  led.clear(); //make sure led is off on startup because it will be a super bright blue otherwise
  led.show();

  //put in normal mode because this is set somewhere else beforehand
  TCCR3A = 0;
  //set prescaler to 64
  TCCR3B = 3;
  //enable timer interupt on overflow
  TIMSK3 = 1;

  Serial1.begin(9600);     // starts up serial communication between arduino and computer

  Serial1.println("linking servos");
  thumb.attach(THUMB_PIN, extendmin, extendmax);    //defines where the servos are and their extendmax/extendmins
  pointer.attach(INDEX_PIN, extendmin, extendmax);
  middle.attach(MIDDLE_PIN, extendmin, extendmax);
  ring.attach(RING_PIN, extendmin, extendmax);
  pinky.attach(PINKY_PIN, extendmin, extendmax);

  pinMode(BUTTON_PIN, INPUT_PULLUP);
  attachInterrupt(digitalPinToInterrupt(BUTTON_PIN), locked, FALLING);

  Serial1.println("Starting");       //makes the hand relax all of the way
  handPosition(extendmax, extendmax, extendmax, extendmax, extendmax);

  Serial1.println("Reading in 3");
  delay(1000);
  Serial1.println("Reading in 2");
  delay(1000);
  Serial1.println("Reading in 1");
  delay(1000);

  trigger = setTrigger();
  isIniting = false;
}

//setup starts by linking the Servo objects to each pin and detailing the limits per each argument. Then it opens the hand for a default position and will call the setTrigger function. Once it's collected, the setup is complete

void loop() {
  float currentVoltage = 0;

  if (!isLocked && check(currentVoltage = analogRead(MYO_PIN))) { // collects voltage, then assigns to currentVoltage, then passes currentVoltage to check function, then checks the check return value to see if it's higher than trigger value

    state = (++state) % (FIST + 1); // increment through available state values

    Serial1.print("state is ");
    Serial1.println(state);

    Serial1.print("myo voltage is: ");
    Serial1.println(currentVoltage); // prints in the Serial1 moniter

    switch (state) {
      case OPEN:
        Serial1.println("Open");
        handPosition(setmax, setmax, setmax, setmax, setmax);
        break;
      case FIST:
        Serial1.println("Fist");
        handPosition(setmin, setmin, setmin, setmin, setmin);
        break;
      case POINT:
        Serial1.println("Point");
        handPosition(extendmax, extendmin, extendmax, extendmax, extendmax);
        break;
      case PINCH:
        Serial1.println("Pinch");
        handPosition(extendmin, extendmin, extendmin, extendmax, extendmax);
        break;
      default:
        state = OPEN; //edgecase if logic fail
        handPosition(extendmax, extendmax, extendmax, extendmax, extendmax);
        break;
    }
  }
}

//the loop function will continously check the users input and assign it to currentVoltage, then it's verified through the check function to see if its higher than the set trigger value from setup, if so then it will switch between the four hand positions in a looping structure

/*int setTrigger(){
  float average = 0;
  int i, j;
  do{
    average = 0;//resets collection value if it failed prior
    for(j = 1; j <= 3; j++){//loops to collect the three impulses
      Serial1.print("Reading impulse ");
      Serial1.print(j);
      Serial1.println(" in the next 3 seconds");
      for(i = 3; i != 0; i--){//counts down 3 seconds
        Serial1.println(i);
        delay(1000);
      }
      Serial1.println("Reading");
      average = average + analogRead(myoIn);//adds up collected values with previous values
      Serial1.print("Total is:");
      Serial1.println(average);

    }

      average = average/3;
      Serial1.print("Average is:");
      Serial1.println(average);
  } while((average) < 200);//if it's less than 200 than we reattempt collection
  return (int)(average);//returns average upon success
  }*/


int setTrigger() {
  float average = 0;
  int i, j;
  int max1, max2, max3;
  int loopcount, starttime, endtime;
  do {
    average = 0;//resets collection value if it failed prior
    max1 = 0;
    max2 = 0;
    max3 = 0;
    loopcount = 0;
    starttime = millis();
    endtime = starttime;
    while ((endtime - starttime) < 3000) // do this loop for about 1 second
    {
      collect(&max1, &max2, &max3);
      loopcount = loopcount + 1;
      endtime = millis();
    }
    average = (max1 + max2 + max3) / 3;
    Serial1.println("max1");
    Serial1.print(max1);
    Serial1.println("max2");
    Serial1.print(max2);
    Serial1.println("max3");
    Serial1.print(max3);
    Serial1.println("average");
    Serial1.println(average);
    Serial1.println("loop");
    Serial1.println(loopcount);
  } while ((average) < 200); //if it's less than 200 than we reattempt collection
  return (int)(average);//returns average upon success
}

void collect(int * max1, int * max2, int * max3) {
  float prevVolt = analogRead(MYO_PIN);
  float currVolt = analogRead(MYO_PIN);
  float nextVolt = analogRead(MYO_PIN);
  if (currVolt < overload && prevVolt < currVolt && currVolt > nextVolt) {
    if (currVolt > *max1) {
      *max1 = currVolt;
      return;
    }
    else if (currVolt > *max2) {
      *max2 = currVolt;
      return;
    }
    else if (currVolt > *max3) {
      *max3 = currVolt;
      return;
    }
  }
}

//setTrigger collects 3 inputs by the user with a 3 second delay between each one. It calculates the average and if it's lower than 200, it's an assumed error and will reset the collection. Once completed it returns the average

bool check(int voltage) {
  return voltage > trigger && voltage < overload;
}

//check collects the voltage, and if it's greater than the trigger value, will return 1 for true, else 0 for false

void locked() {
  static unsigned long last_lock_time = 0;

  if (last_lock_time > millis()) // if the last lock time is in the future, there probably was an overflow so we should reset
    last_lock_time = 0;

  if (millis() - last_lock_time > 1000) { // only change state once a second to prevent button bouncing issues
    last_lock_time = millis();
    isLocked = !isLocked;
    Serial1.print("Button State: ");
    Serial1.println(isLocked);
  }
}

void handPosition(int thumbPos, int pointerPos, int middlePos, int ringPos, int pinkyPos) {
  //function hand position takes in 5 integer inputs for each finger and moves the servos according to
  //each input. for the servos, extendmaximum extension is 1000 and extendminimum (all the way in) is 2000.
  //this is a function from the servo.h library basically gives the pulse width
  pointer.writeMicroseconds(pointerPos);
  middle.writeMicroseconds(middlePos);
  ring.writeMicroseconds(ringPos);
  pinky.writeMicroseconds(pinkyPos);
  delay(200);
  thumb.writeMicroseconds(thumbPos+150); //this is because the thumb is not tied tight
  delay(1000);       //this is so the servos have time to get to their set position
  thumb.writeMicroseconds(thumb.readMicroseconds()); //adjusts servos to adjust desired position to actual position reached to avoid burnout
  pointer.writeMicroseconds(pointer.readMicroseconds());
  middle.writeMicroseconds(middle.readMicroseconds());
  ring.writeMicroseconds(ring.readMicroseconds());
  pinky.writeMicroseconds(pinky.readMicroseconds());
  delay(250);
}

//handPosition takes 5 integer values to be set to each servo for the finger, with one second of time to adjust, their position is read and if not accurate, will adjust servo command to stay at the position

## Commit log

2020-01-25 Added old files
    [Backcover 12-6-19.SLDPRT, Backcover 12-6-19.STL]
2020-01-25 renamed directories added v0.1 pcb
    [191216_Backcover_JD.SLDPRT, 191216_Backcover_JD.STL, Backcover 12-6-19.SLDPRT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]
2020-01-25 added v1.1 and v2.0 boards
    [Hand v2.0.kicad_pcb, Hand v2.0.sch, circuitdraft.brd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]
2020-01-25 added version silkscreen to v1.1 board
    [circuitdraft.brd]
2020-01-25 v1.1 shifted silkscreen text
    [circuitdraft.brd]
2020-01-25 v2.0 added version silkscreen and renamed files
    [Hand v2.0.kicad_pcb]
2020-01-27 v2.0 fixed file naming issues
    [Hand v2.0.sch]
2020-01-31 readded v1.2 because oops
    [circuitdraft.brd, circuitdraft.sch]
2020-02-01 Added switch. Passes DRC
    Final 1.2
    [circuitdraft.brd, circuitdraft.sch]
2020-02-01 Added jack's cover
    hope this works
    [191216_Backcover_JD.SLDPRT]
2020-02-01 Added palm .stl
2020-02-01 Renamed Folder SolidWorks
    [191216_Backcover_JD.SLDPRT]
2020-02-01 Update Readme. Rename Backover
    [203101_Backcover.SLDPRT]
2020-02-01 began swapping arm chips
    [Hand v2.0.kicad_pcb, Hand v2.0.sch]
2020-02-01 rename 2.0 to 2.1 for chip change
    [Hand v2.1.kicad_pcb, Hand v2.1.sch]
2020-02-01 undo oops by readding v2.0
    [Hand v2.0.kicad_pcb, Hand v2.0.sch]
2020-02-01 created servo holder for test bed
    [servo holder v1.stl]
2020-02-01 Create electronics v1.0 holder v1.stl
    [electronics v1.0 holder v1.stl]
2020-02-02 finished adding STM32F303VCT6
    [Hand v2.1.kicad_pcb, Hand v2.1.sch]
2020-02-02 cleaned up silkscreen and updated version on silkscreen
    [Hand v2.1.kicad_pcb]
2020-02-03 Removed Back Shell
    [2020_03_02_BackcoverShell.SLDPRT]
2020-02-03 refined test bed mounts
    [actuonix PQ12 servo holder.stl, electronics v1.0 holder v1.stl, electronics v1.0 holder.stl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]
2020-02-04 Create STM32F3DISCOVERY holder.stl
    [STM32F3DISCOVERY holder.stl]
2020-02-04 removed need for supports and made discovery board holder shorter and shifted holes
    [STM32F3DISCOVERY holder.stl, actuonix PQ12 servo holder.stl, electronics v1.0 holder.stl]
2020-02-09 connected unused IO pins on MCU to ground
    [Hand v2.1.kicad_pcb, Hand v2.1.sch]
2020-02-09 Create 400 point breadboard holder.stl
    [400 point breadboard holder.stl]
2020-02-09 Create battery holder.stl
    [battery holder.stl]
2020-02-10 Update 400 point breadboard holder.stl
    [400 point breadboard holder.stl]
2020-02-20 Added solid parts
    [02_18_2020_BackcoverF.SLDPRT, 2020_03_02_BackcoverShell.SLDPRT, 203101_Backcover.SLDPRT]
2020-02-20 Started moving timing chip
    [circuitdraft.brd, circuitdraft.sch]
2020-02-21 Started ahmad's changes
    [circuitdraft.brd]
2020-02-23 Created a SLDPRT file to manipulte in Blender. Foundation of new plam.
    [New Palm.SLDPRT]
2020-02-27 New Palm has been updated
    [New Palm.SLDPRT]
2020-02-27 restored files
    [Legiment Jig.STL]
2020-03-01 Easier to print
    [circuitdraft.brd]
2020-03-03 Jacks changes
    [circuitdraft.brd, circuitdraft.sch]
2020-03-03 fix thumb pin
2020-03-03 added reset pull-up resistor
2020-03-03 zone refill
    [Hand v2.1.kicad_pcb]
2020-03-07 new palm
    [New Palm STL.STL, New Palm.SLDPRT]
2020-03-08 enabled regulators and removed unneeded part
    [Hand v2.1.kicad_pcb, Hand v2.1.sch]
2020-03-08 updated name of battery to be clearer
    [Hand v2.1.kicad_pcb, Hand v2.1.sch]
2020-03-09 Added dimensions for servo inlets in the new palm design
    [New Palm.SLDPRT]
2020-03-12 Changed so servo does not grab so far
2020-04-13 Worked on myosensor
    [Myosense.v1.brd, Myosense.v1.sch]
2020-04-29 Myosensor board and library change
    [Myosense.v1.sch]
2020-05-21 Updated myosensor
    [Myosense.v1.brd]
2020-05-31 created v3 project
    [hand v3.0.kicad_pcb, hand v3.0.sch]
2020-06-03 testing 1.2 charger
2020-06-05 started on power for 3.0
2020-06-06 motor and motor drivers configured
    [hand v3.0.sch]
2020-09-17 added bom

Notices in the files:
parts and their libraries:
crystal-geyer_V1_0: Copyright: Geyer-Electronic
